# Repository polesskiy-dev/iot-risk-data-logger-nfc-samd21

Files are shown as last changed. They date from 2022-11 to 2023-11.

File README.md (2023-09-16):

# IoT Risk Data Logger

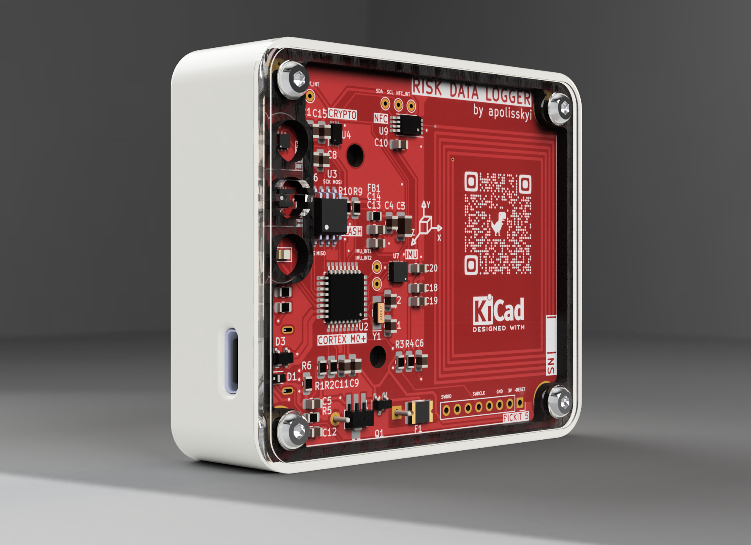
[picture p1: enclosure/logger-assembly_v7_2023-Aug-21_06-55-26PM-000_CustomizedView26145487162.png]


## Introduction
Fully open-source and open-hardware **data logger** tailored for logistics applications i.e. for cold chain monitoring systems.

## Hardware

[Schematics, PCB, enclosure, BOM, assembly documentation](https://github.com/polesskiy-dev/iot-risk-data-logger-nfc-samd21-hardware)

### Features

#### Key risk metrics:
- Temperature/Humidity [Sensirion SHT3x](https://sensirion.com/media/documents/213E6A3B/63A5A569/Datasheet_SHT3x_DIS.pdf)
- Ambient Light Sensor [TI OPT3001](https://www.ti.com/lit/ds/symlink/opt3001.pdf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)
- Shock Sensor - Accelerometer [NXP MMA8452Q](https://www.nxp.com/docs/en/data-sheet/MMA8452Q.pdf)

#### Communication:
- USB-C:
    - MSD: Device works ad a flash drive to direct log read on PC
    - CDC: Console for debug and firmware bootloader
- NFC for control through mobile app [ST ST25DV04K](https://www.st.com/resource/en/datasheet/st25dv04k.pdf)

#### Security:
- Hardware crypto [Microchip ATECC608A](https://www.microchip.com/wwwproducts/en/ATECC608A) for:
    - Firmware encryption for bootloader
    - Log data encryption
    - Authentication (X509 certificates for IoT platforms)

#### Power:
- Powered by 2xAAA batteries or USB-C (reverse polarity protection, OR source selection)
- Low Power Consumption: Ultra-low power architecture, ~ one year of data acquisition

#### Additional Features:
- 4MB SPI NOR Flash [AT25DF321](https://www.mouser.com/catalog/specsheets/atmel_doc3669.pdf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)
- RTC Clock: accurate 32.768Hz quartz oscillator
- LED: Simple indication for device states

#### Main MCU
- [Microchip ATSAMD21E18](https://www.microchip.com/en-us/product/atsamd21e18) - 32-bit ARM Cortex-M0+ MCU, 48MHz, 256KB of flash and 32KB of SRAM. Satisfies AEC-Q100, recommended for Automotive.

## Firmware

The firmware is written in C with a bare-metal approach and exclusively uses static memory allocation. It is developed on top of the [Harmony v3](https://www.microchip.com/en-us/tools-resources/configure/mplab-harmony) Embedded Software framework. Developed with [MPLAB X](https://www.microchip.com/en-us/tools-resources/develop/mplab-x-ide), [XC32](https://www.microchip.com/en-us/tools-resources/develop/mplab-xc-compilers) compiler.

### Main architecture

The source code adheres to an asynchronous, non-blocking programming style designed to achieve ultra-low power consumption.

The core mechanism revolves around handling asynchronous events from a queue and entering a low-power sleep state when the queue is empty. New events are enqueued either through interrupts (e.g., cron-scheduled sensor reads) or through the main system loop.

The architecture incorporates the following key concepts:
- [Event Loop](https://en.wikipedia.org/wiki/Event_loop)
- [Actor Model](https://en.wikipedia.org/wiki/Actor_model) - aka [Active Object](https://en.wikipedia.org/wiki/Active_object)
- [Finite-state machine](https://en.wikipedia.org/wiki/Finite-state_machine) - [Mealy](https://en.wikipedia.org/wiki/Mealy_machine) + [Moore](https://en.wikipedia.org/wiki/Moore_machine) implementation

To streamline development, an Active Object + FSM library has been implemented and is maintained in a separate [active-object-fsm](https://github.com/polesskiy-dev/active-object-fsm) repository.

## Installation
    
    $ git clone https://github.com/polesskiy-dev/iot-risk-data-logger-nfc-samd21 --recurse-submodules

Update submodules to the latest version (optional):

    $ git submodule init && git submodule update --remote # install submodules

## Some dev process photos:

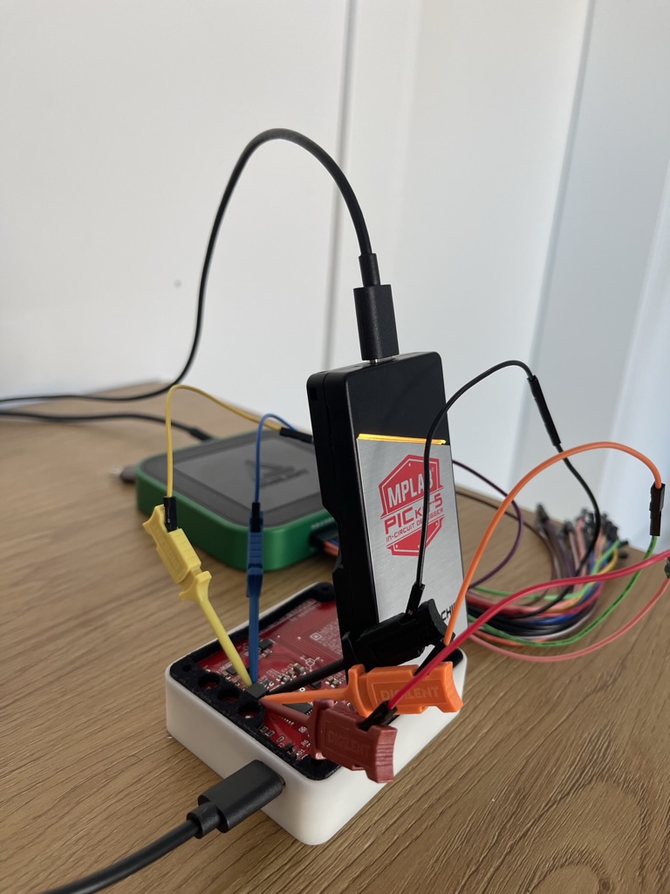
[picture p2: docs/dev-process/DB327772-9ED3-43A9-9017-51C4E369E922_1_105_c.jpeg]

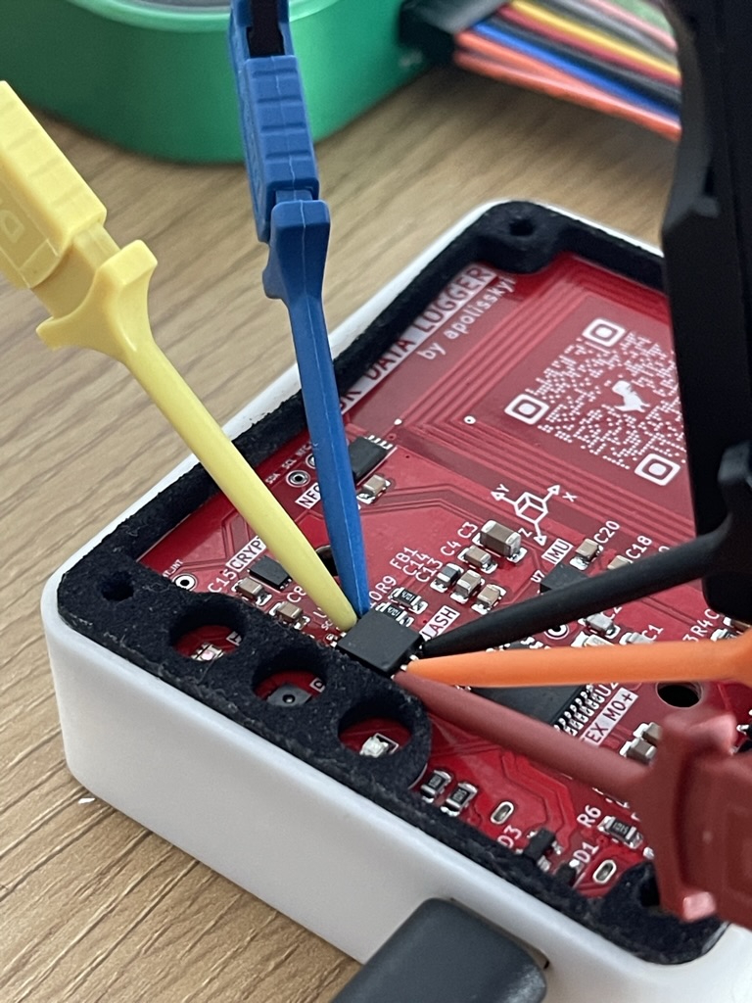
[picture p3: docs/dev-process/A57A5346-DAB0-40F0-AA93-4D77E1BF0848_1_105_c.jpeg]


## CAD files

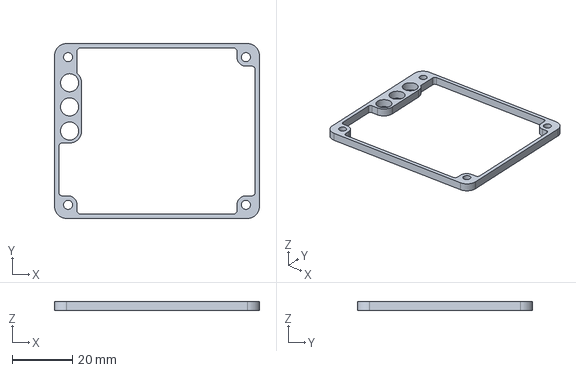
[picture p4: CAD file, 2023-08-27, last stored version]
enclosure/3D-print-manufacturing/Logger gasket v16.step
68.0 x 58.0 x 3.00 mm

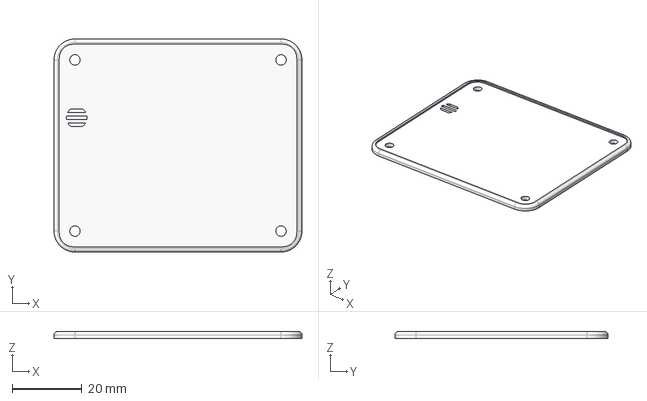
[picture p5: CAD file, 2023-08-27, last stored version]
enclosure/3D-print-manufacturing/Logger transparent top v9.step
71.0 x 61.0 x 2.00 mm

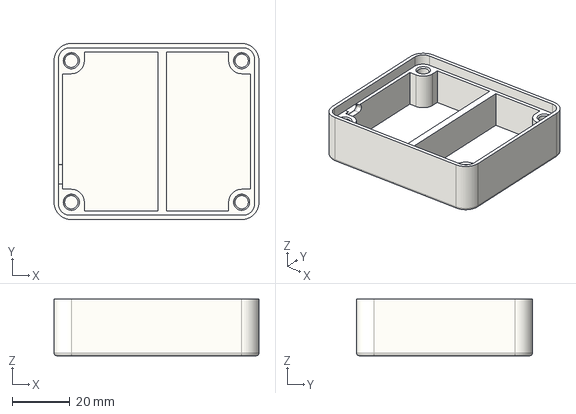
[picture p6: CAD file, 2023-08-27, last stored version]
enclosure/3D-print-manufacturing/Logger bottom enclosure v32.step
71.0 x 61.0 x 19.6 mm

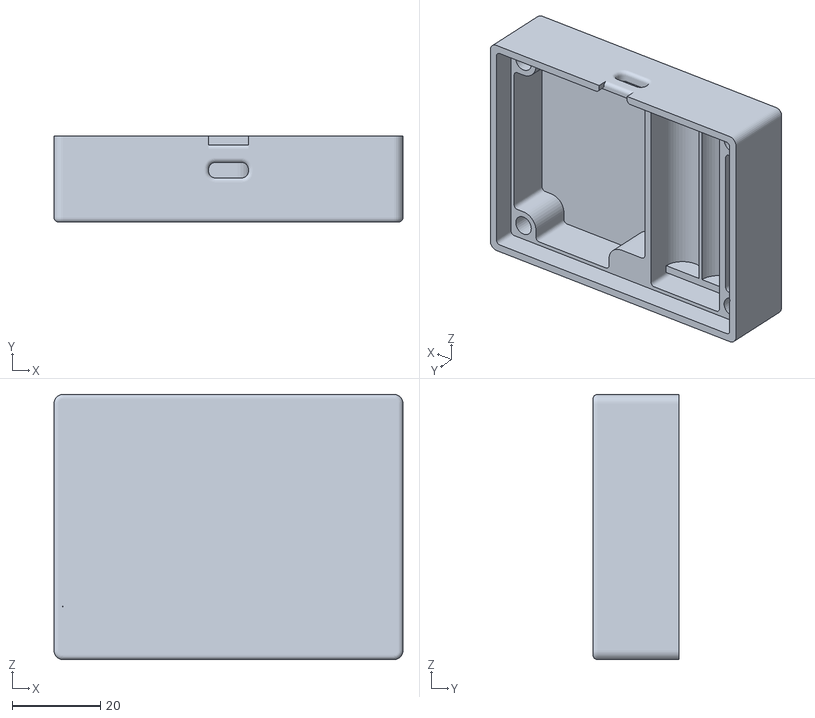
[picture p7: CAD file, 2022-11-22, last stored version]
hardware/enclosure/iot-data-logger-enclosure-bottom-base v35.stl
79.0 x 19.5 x 60.0

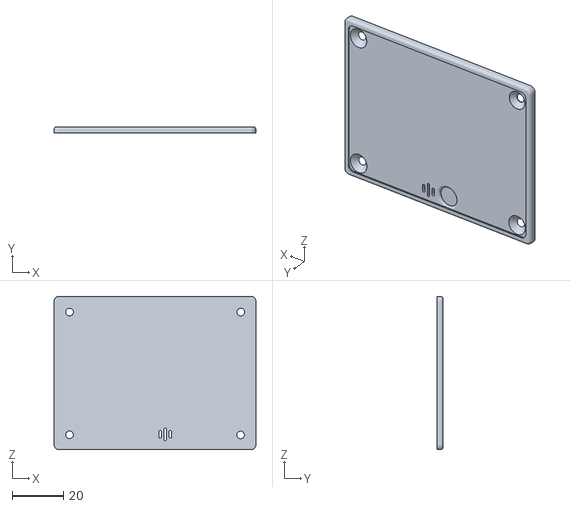
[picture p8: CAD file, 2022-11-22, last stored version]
hardware/enclosure/iot-data-logger-enclosure-top-cover v19.stl
79.0 x 2.50 x 60.0

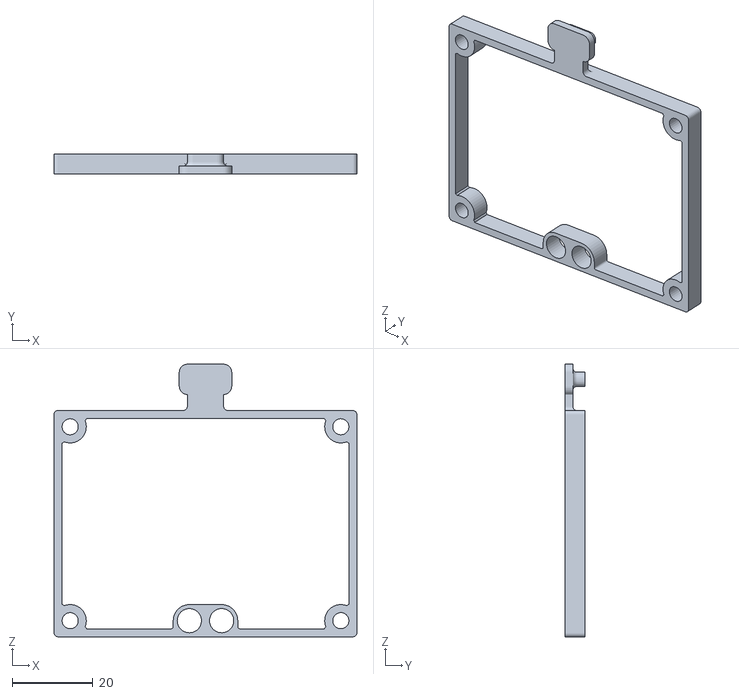
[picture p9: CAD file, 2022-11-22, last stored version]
hardware/enclosure/iot-data-logger-enclosure-gasket v30.stl
75.0 x 5.00 x 67.5

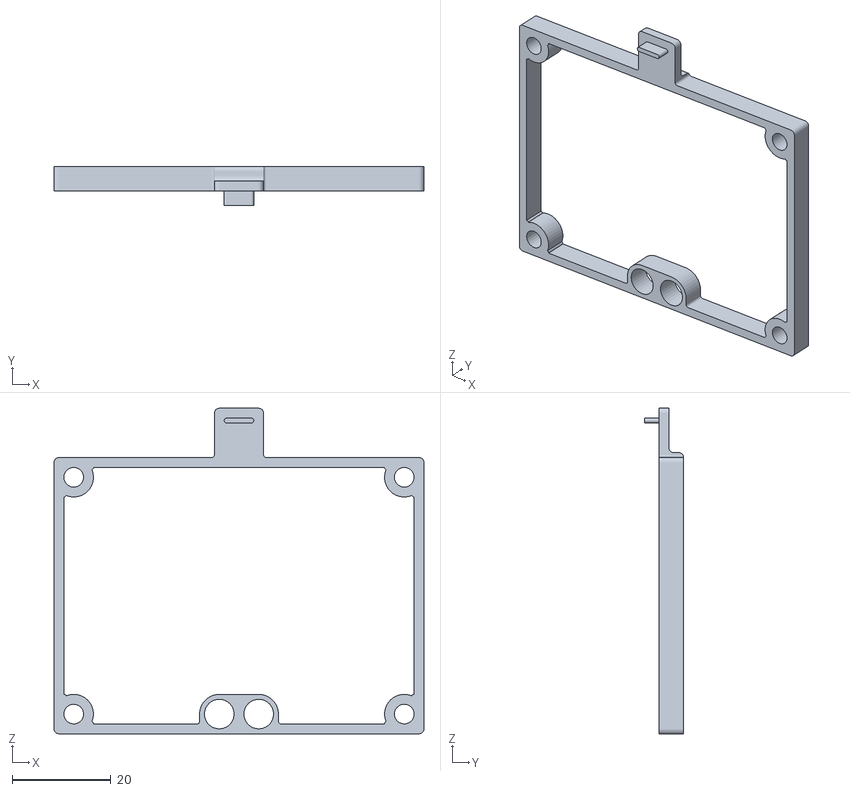
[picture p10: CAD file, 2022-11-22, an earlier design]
hardware/enclosure/iot-data-logger-enclosure-gasket v4.stl
75.0 x 8.00 x 66.0

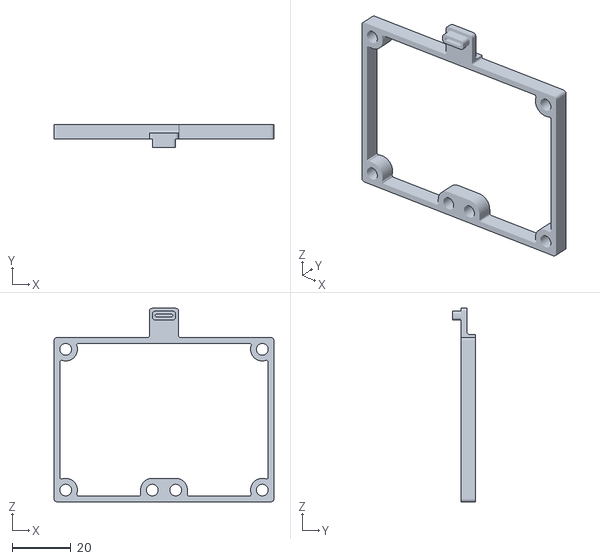
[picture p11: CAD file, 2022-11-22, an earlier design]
hardware/enclosure/iot-data-logger-enclosure-gasket v1.stl
75.0 x 8.00 x 66.0

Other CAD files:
hardware/enclosure/iot-data-logger-enclosure-top-cover v9.stl
hardware/enclosure/iot-data-logger-enclosure-bottom-base v18.stl
hardware/enclosure/iot-data-logger-enclosure-bottom-base v19.f3d
hardware/enclosure/iot-data-logger-enclosure-bottom-base v35.f3d
hardware/enclosure/iot-data-logger-enclosure-gasket v4.f3d
hardware/enclosure/iot-data-logger-enclosure-gasket v8.f3d
hardware/enclosure/iot-data-logger-enclosure-top-cover v9.f3d

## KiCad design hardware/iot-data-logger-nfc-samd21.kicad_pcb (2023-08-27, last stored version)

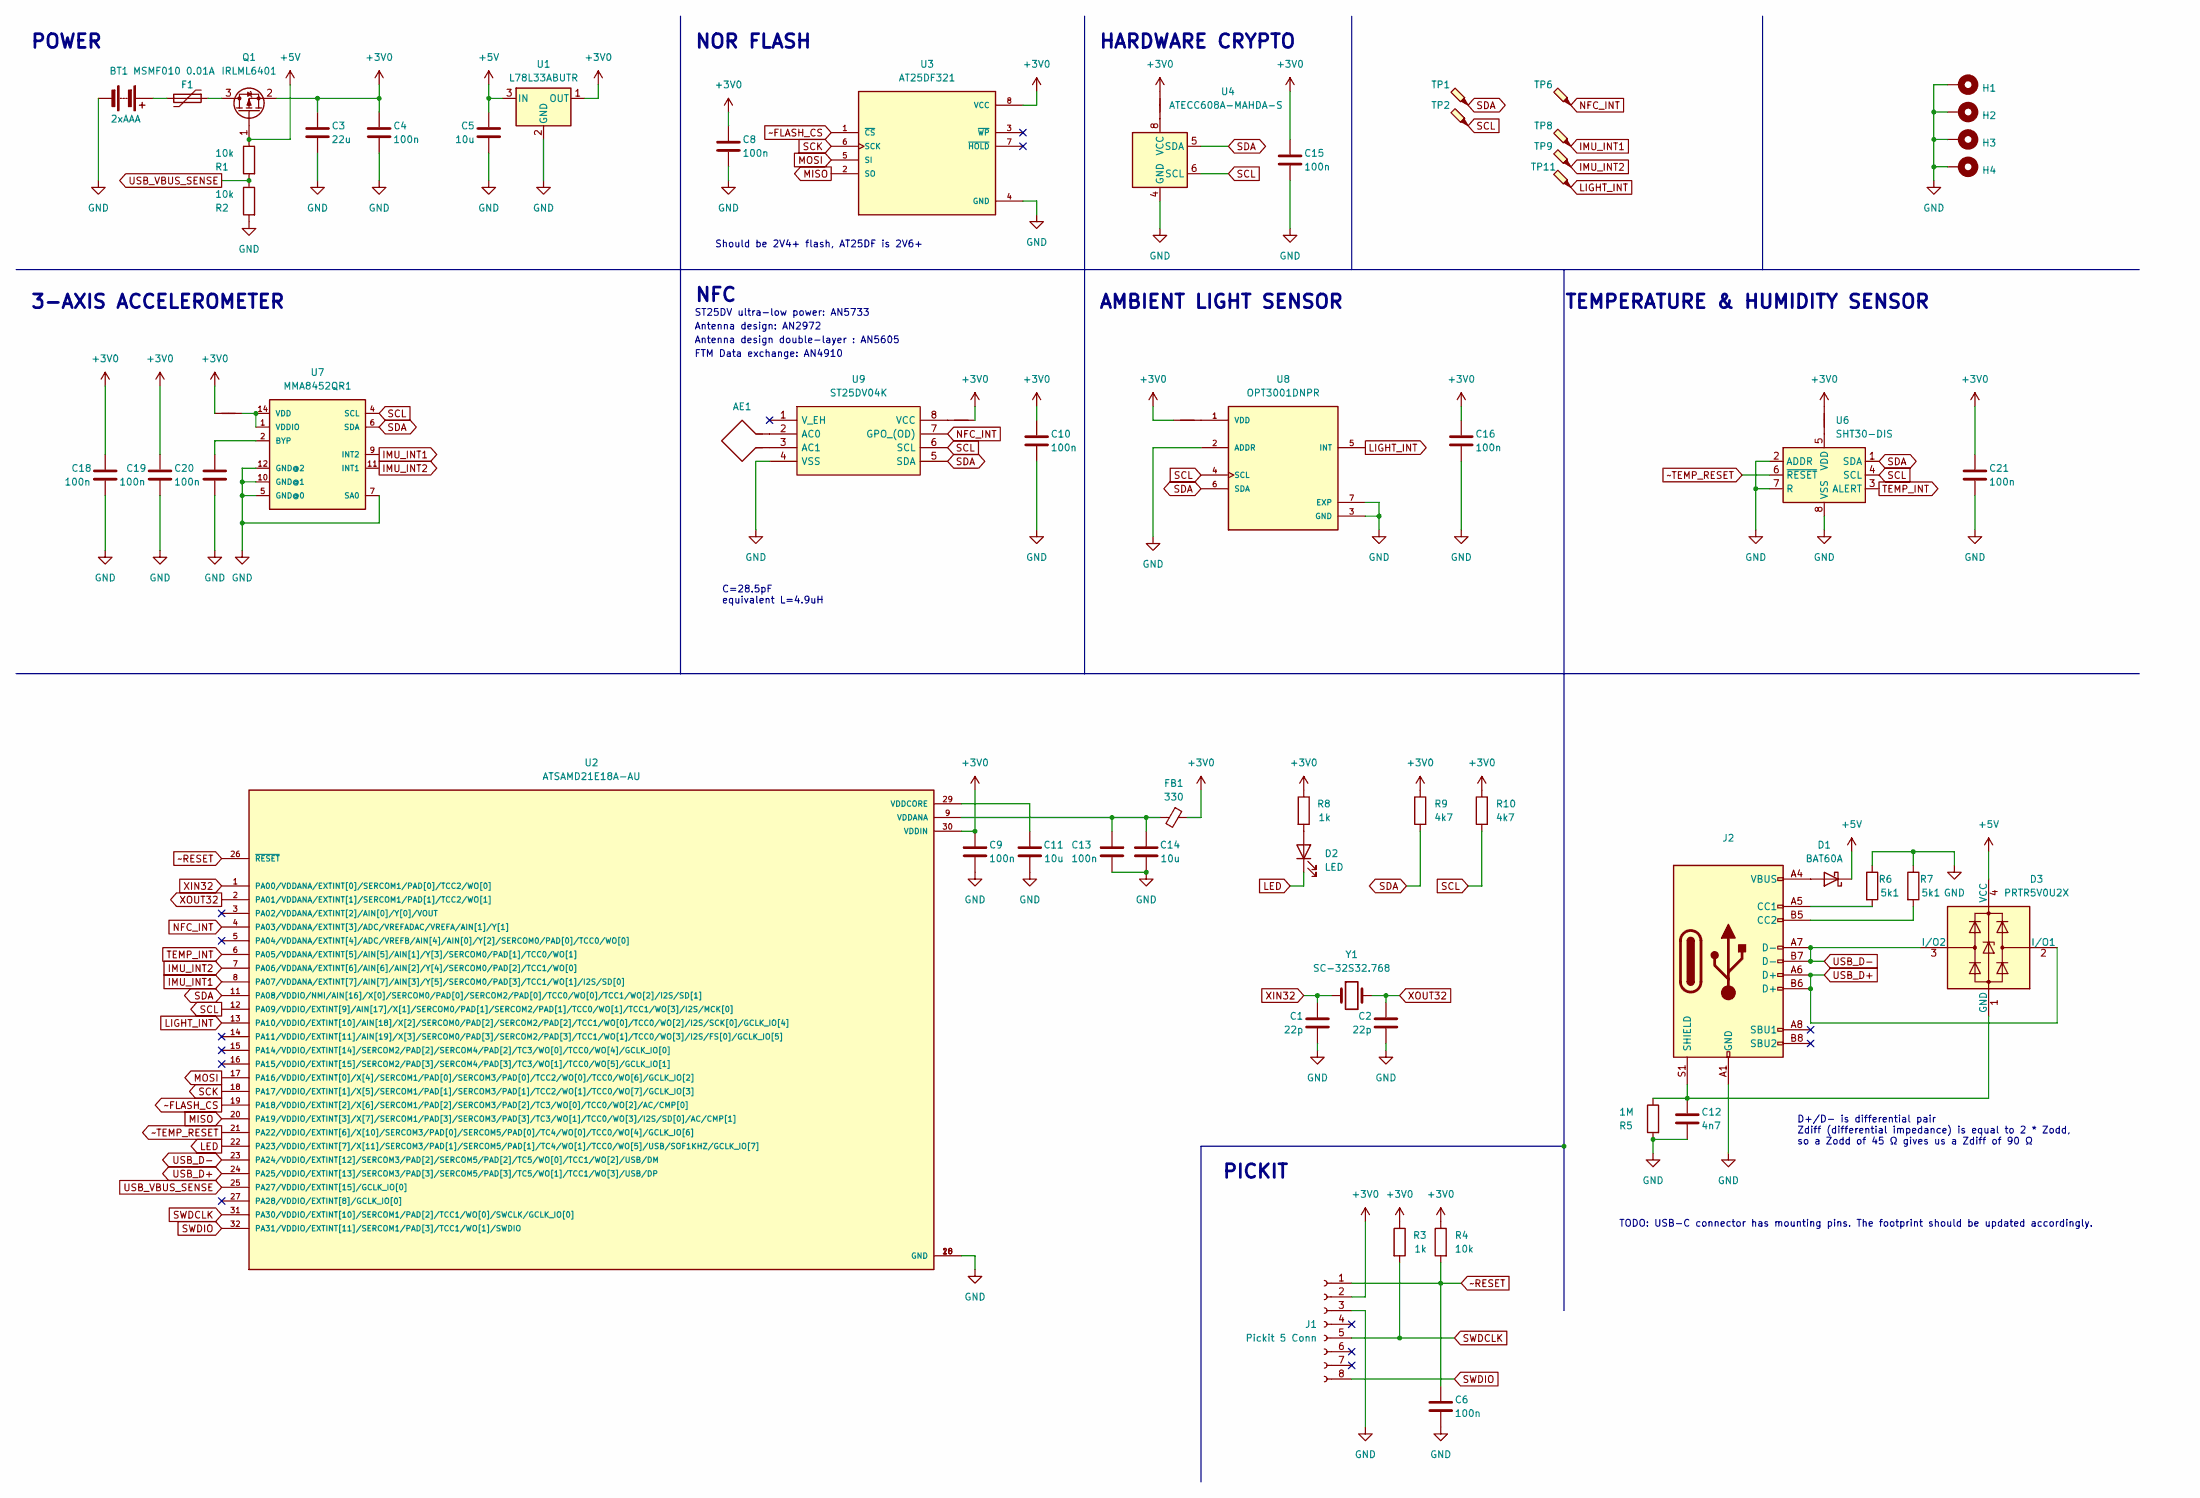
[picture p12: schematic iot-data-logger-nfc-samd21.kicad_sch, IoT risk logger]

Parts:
AE1: Antenna_Loop; ANT_NFC_30x40
BT1: 2xAAA; BatteryHolder_Keystone_2468_2xAAA; Part Keystone 2468; LCSC Part C254917
C1, C2: 22p; C_0805_2012Metric_Pad1.18x1.45mm_HandSolder; Part CL21C220JBANNNC; LCSC Part C1804
C3: 22u; C_1206_3216Metric_Pad1.33x1.80mm_HandSolder; Part CL31A226KAHNNNE; LCSC Part C12891
C4, C6, C8, C9, C10, C13, C15, C16, C18, C19, C20, C21: 100n; C_0805_2012Metric_Pad1.18x1.45mm_HandSolder; Part CL21B104KBCNNNC; LCSC Part C1711
C5, C11, C14: 10u; C_0805_2012Metric_Pad1.18x1.45mm_HandSolder; Part CL21A106KOQNNNE; LCSC Part C1713
C12: 4n7; C_0805_2012Metric_Pad1.18x1.45mm_HandSolder; Part CL21B472KBANNNC; LCSC Part C50131
D1: BAT60A; D_SOD-323_HandSoldering; Part BAT60A; LCSC Part C5355496
D2: LED; LED_0805_2012Metric_Pad1.15x1.40mm_HandSolder; Part NCD0805G1; LCSC Part C84260
D3: PRTR5V0U2X; SOT-143; Part PRTR5V0U2X; LCSC Part C2827688
F1: MSMF010 0.01A; Fuse_1812_4532Metric_Pad1.30x3.40mm_HandSolder; Part MF-MSMF010-2; LCSC Part C12430
FB1: 330; R_0805_2012Metric_Pad1.20x1.40mm_HandSolder; Part BLM21PG331SN1D; LCSC Part C47130
H1, H2, H3, H4: MountingHole_Pad; MountingHole_3.2mm_M3_Pad_Via
J1: Pickit 5 Conn; PinSocket_1x08_P2.54mm_Vertical
J2: USB Type-C; USB_C_Receptacle_XKB_U262-16XN-4BVC11; Part KH-TYPE-C-16P; LCSC Part C709357
NT1, NT2, NT3, NT4, NT5: NetTie_2; NetTie-2_SMD_Pad0.5mm
Q1: IRLML6401; SOT-23; Part IRLML6401TRPBF; LCSC Part C3034
R1, R2, R4: 10k; R_0805_2012Metric_Pad1.20x1.40mm_HandSolder; Part RC0805FR-0710KL; LCSC Part C84376
R3, R8: 1k; R_0805_2012Metric_Pad1.20x1.40mm_HandSolder; Part RC0805FR-071KL; LCSC Part C95781
R5: 1M; R_0805_2012Metric_Pad1.20x1.40mm_HandSolder; Part RC0805FR-071ML; LCSC Part C107700
R6, R7: 5k1; R_0805_2012Metric_Pad1.20x1.40mm_HandSolder; Part RC0805FR-075K1L; LCSC Part C84375
R9, R10: 4k7; R_0805_2012Metric_Pad1.20x1.40mm_HandSolder; Part RC0805FR-074K7L; LCSC Part C60816
TP1, TP2, TP6, TP8, TP9, TP11: TestPoint_Probe; TestPoint_THTPad_D1.5mm_Drill0.7mm
U1: L78L33ABUTR; SOT-89-3_Handsoldering; Part L78L33ABUTR; LCSC Part C81362
U2: ATSAMD21E18A-AU; TQFP-32_7x7mm_P0.8mm; Part ATSAMD21E18A-AU; LCSC Part C618771
U3: AT25DF321; SOP-8_5.28x5.23mm_P1.27mm; Part AT25DF321A-SH-T; LCSC Part C6490
U4: ATECC608A-MAHDA-S; DFN-8-1EP_3x2mm_P0.5mm_EP1.3x1.5mm; Part ATECC608A-MAHDA-S; LCSC Part C616908
U6: SHT30-DIS; Sensirion_DFN-8-1EP_2.5x2.5mm_P0.5mm_EP1.1x1.7mm; Part SHT30-DIS-B10KS; LCSC Part C2687423
U7: MMA8452QR1; XDCR_MMA8452QR1; Part MMA8452QR1; LCSC Part C11360
U8: OPT3001DNPR; SON65P200X200X65-7N; Part OPT3001DNPR; LCSC Part C90462
U9: ST25DV04K; TSSOP-8_4.4x3mm_P0.65mm; Part ST25DV04K-IER6T3; LCSC Part C2654816
Y1: SC-32S32.768; Crystal_SMD_EuroQuartz_EQ161-2Pin_3.2x1.5mm_HandSoldering; Part SC-32S32.768kHz20PPM12.5pF; LCSC Part C97606

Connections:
+3V0: C3.1, C4.1, C8.1, C9.1, C10.1, C15.1, C16.1, C18.1, C19.1, C21.1, FB1.1, J1.2, NT1.1, NT2.1, NT3.2, NT4.1, NT5.2, Q1.2 (S), R3.1, R4.1, R8.1, R9.1, R10.1, U1.1 (OUT), U2.30 (VDDIN), U3.8 (VCC)
+5V: C5.1, D1.1 (K), D3.4 (VCC), Q1.1 (G), R1.1, U1.3 (IN)
GND: BT1.2 (-), C1.2, C2.2, C3.2, C4.2, C5.2, C6.2, C8.2, C9.2, C10.2, C11.2, C12.2, C13.2, C14.2, C15.2, C16.2, C18.2, C19.2, C20.2, C21.2, H1.1, H2.1, H3.1, H4.1, J1.3, J2.A1 (GND), J2.A12 (GND), J2.B1 (GND), J2.B12 (GND), R2.2, R5.2, R6.1, R7.1, U1.2 (GND), U2.10 (GND), U2.28 (GND), U3.4 (GND), U4.4 (GND), U6.2 (ADDR), U6.7 (R), U6.8 (VSS), U6.9 (VSS), U7.5 (GND@0), U7.7 (SA0), U7.10 (GND@1), U7.12 (GND@2), U8.2 (ADDR), U8.3 (GND), U8.7 (EXP), U9.4 (VSS)
IMU_INT1: TP8.1, U2.8 (PA07/VDDANA/EXTINT[7]/AIN[7]/AIN[3]/Y[5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), U7.9 (INT2)
IMU_INT2: TP9.1, U2.7 (PA06/VDDANA/EXTINT[6]/AIN[6]/AIN[2]/Y[4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), U7.11 (INT1)
LED: D2.1 (K), U2.22 (PA23/VDDIO/EXTINT[7]/X[11]/SERCOM3/PAD[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)
LIGHT_INT: TP11.1, U2.13 (PA10/VDDIO/EXTINT[10]/AIN[18]/X[2]/SERC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), U8.5 (INT)
MISO: U2.20 (PA19/VDDIO/EXTINT[3]/X[7]/SERCOM1/PAD[3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), U3.2 (SO)
MOSI: U2.17 (PA16/VDDIO/EXTINT[0]/X[4]/SERCOM1/PAD[0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), U3.5 (SI)
NFC_INT: TP6.1, U2.4 (PA03/VDDANA/EXTINT[3]/ADC/VREFADAC/VREF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), U9.7 (GPO_(OD))
unnamed: BT1.1 (+), F1.2
unnamed: D1.2 (A), J2.A4 (VBUS), J2.A9 (VBUS), J2.B4 (VBUS), J2.B9 (VBUS)
unnamed: D2.2 (A), R8.2
unnamed: C12.1, D3.1 (GND), J2.S1 (SHIELD), R5.1
unnamed: J2.A5 (CC1), R6.2
unnamed: J2.B5 (CC2), R7.2
unnamed: F1.1, Q1.3 (D)
unnamed: C13.1, C14.1, FB1.2, U2.9 (VDDANA)
unnamed: C11.1, U2.29 (VDDCORE)
unnamed: NT1.2, U4.8 (VCC)
unnamed: NT5.1, U6.5 (VDD)
unnamed: C20.1, U7.2 (BYP)
unnamed: NT2.2, U7.1 (VDDIO), U7.14 (VDD)
unnamed: NT4.2, U8.1 (VDD)
unnamed: AE1.2, U9.2 (AC0)
unnamed: AE1.1, U9.3 (AC1)
unnamed: NT3.1, U9.8 (VCC)
SCK: U2.18 (PA17/VDDIO/EXTINT[1]/X[5]/SERCOM1/PAD[1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), U3.6 (SCK)
SCL: R10.2, TP2.1, U2.12 (PA09/VDDIO/EXTINT[9]/AIN[17]/X[1]/SERCO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), U4.6 (SCL), U6.4 (SCL), U7.4 (SCL), U8.4 (SCL), U9.6 (SCL)
SDA: R9.2, TP1.1, U2.11 (PA08/VDDIO/NMI/AIN[16]/X[0]/SERCOM0/PAD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), U4.5 (SDA), U6.1 (SDA), U7.6 (SDA), U8.6 (SDA), U9.5 (SDA)
SWDCLK: J1.5, R3.2, U2.31 (PA30/VDDIO/EXTINT[10]/SERCOM1/PAD[2]/TC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)
SWDIO: J1.8, U2.32 (PA31/VDDIO/EXTINT[11]/SERCOM1/PAD[3]/TC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)
TEMP_INT: U2.6 (PA05/VDDANA/EXTINT[5]/AIN[5]/AIN[1]/Y[3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), U6.3 (ALERT)
USB_D+: D3.2 (I/O1), J2.A6 (D+), J2.B6 (D+), U2.24 (PA25/VDDIO/EXTINT[13]/SERCOM3/PAD[3]/SE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)
USB_D-: D3.3 (I/O2), J2.A7 (D-), J2.B7 (D-), U2.23 (PA24/VDDIO/EXTINT[12]/SERCOM3/PAD[2]/SE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)
USB_VBUS_SENSE: R1.2, R2.1, U2.25 (PA27/VDDIO/EXTINT[15]/GCLK_IO[0])
XIN32: C1.1, U2.1 (PA00/VDDANA/EXTINT[0]/SERCOM1/PAD[0]/TC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), Y1.1
XOUT32: C2.1, U2.2 (PA01/VDDANA/EXTINT[1]/SERCOM1/PAD[1]/TC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), Y1.2
~FLASH_CS: U2.19 (PA18/VDDIO/EXTINT[2]/X[6]/SERCOM1/PAD[2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), U3.1 (~CS)
~RESET: C6.1, J1.1, R4.2, U2.26 (~RESET)
~TEMP_RESET: U2.21 (PA22/VDDIO/EXTINT[6]/X[10]/SERCOM3/PAD[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), U6.6 (~RESET)

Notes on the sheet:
Antenna design double-layer : AN5605
HARDWARE CRYPTO
FTM Data exchange: AN4910
TODO: USB-C connector has mounting pins. The footprint should be updated accordingly.
NFC
С=28.5pF equivalent L=4.9uH
D+/D- is differential pair Zdiff (differential impedance) is equal to 2 * Zodd, so a Zodd of 45 Ω gives us a Zdiff of 90 Ω
Antenna design: AN2972
POWER
ST25DV ultra-low power: AN5733
Should be 2V4+ flash, AT25DF is 2V6+
3-AXIS ACCELEROMETER
PICKIT
NOR FLASH
TEMPERATURE & HUMIDITY SENSOR
AMBIENT LIGHT SENSOR

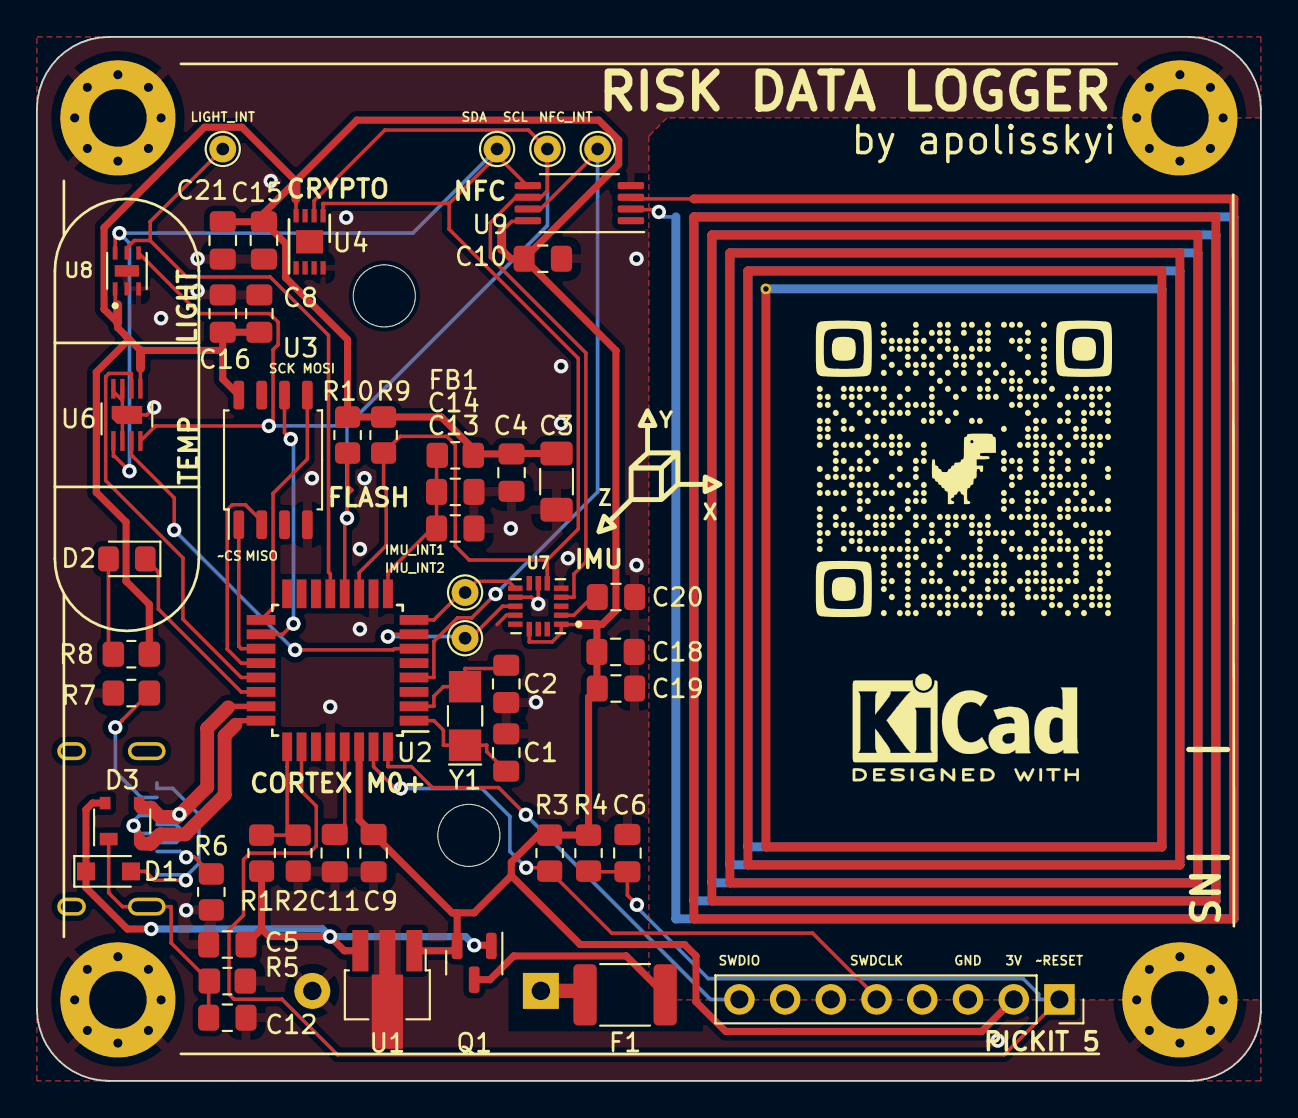
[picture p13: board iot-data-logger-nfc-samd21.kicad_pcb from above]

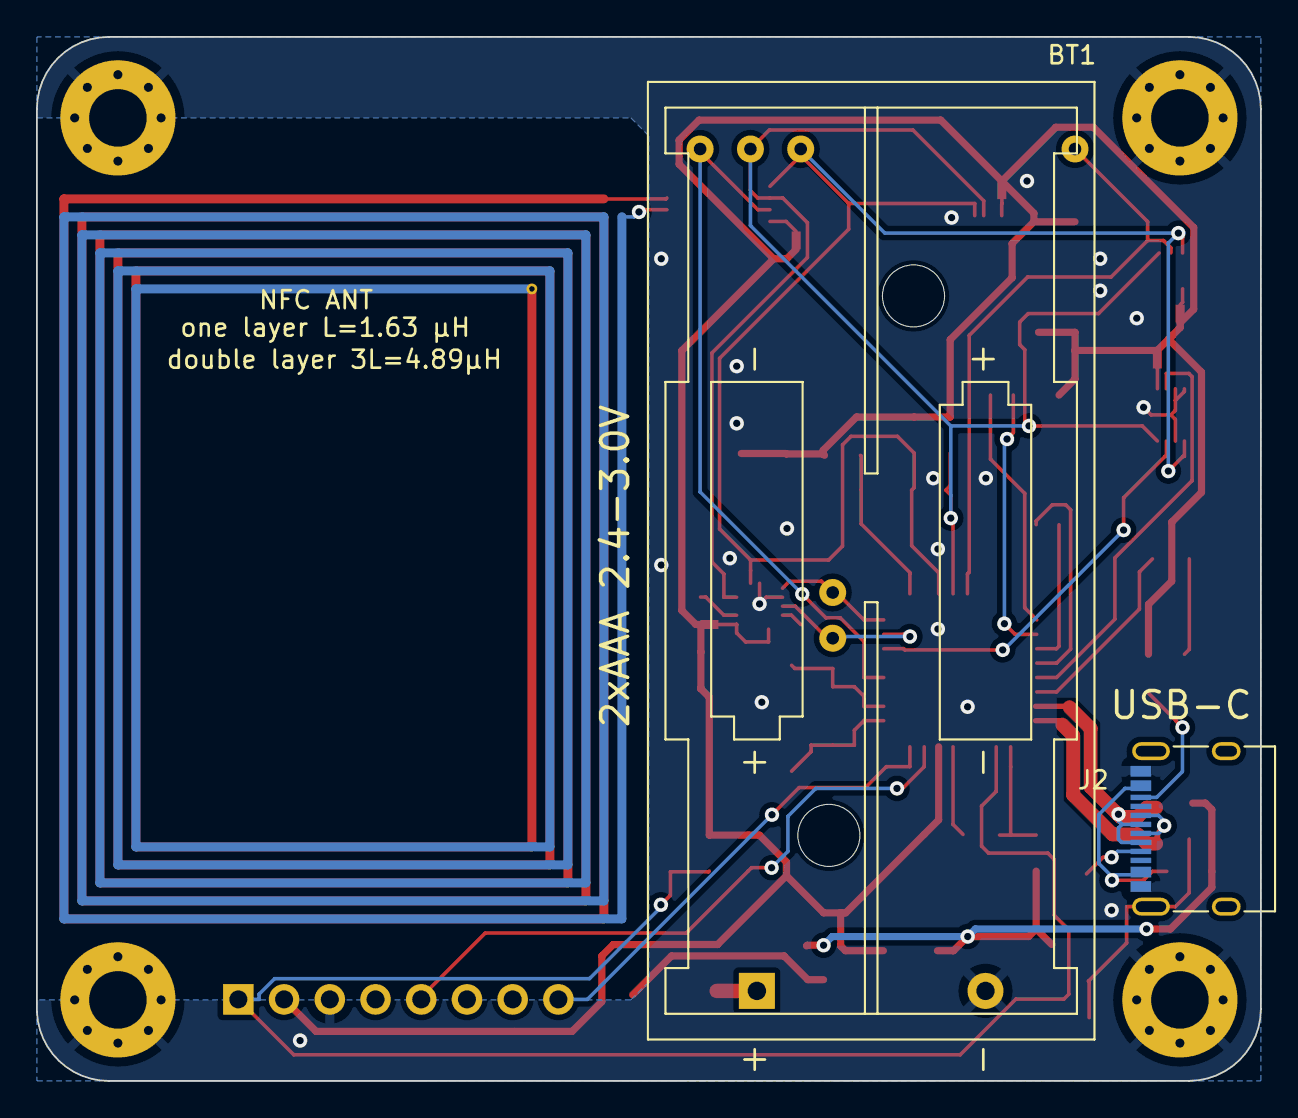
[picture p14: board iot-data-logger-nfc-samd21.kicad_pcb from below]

Board: 2 copper layers, 68.0 x 58.0 mm, 64 parts (2 on the bottom side), 41 nets.

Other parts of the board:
G04: LOGO

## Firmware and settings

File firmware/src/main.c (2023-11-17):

/*******************************************************************************
  Main Source File

  Company:
    Microchip Technology Inc.

  File Name:
    main.c

  Summary:
    This file contains the "main" function for a project.

  Description:
    This file contains the "main" function for a project.  The
    "main" function calls the "SYS_Initialize" function to initialize the state
    machines of all modules in the system
 *******************************************************************************/

// *****************************************************************************
// *****************************************************************************
// Section: Included Files
// *****************************************************************************
// *****************************************************************************

#include <stddef.h>                     // Defines NULL
#include <stdbool.h>                    // Defines true
#include <stdlib.h>                     // Defines EXIT_FAILURE

#include "definitions.h"                // SYS function prototypes
#include "init_manager/init_manager.h"
#include "config/common.defs.h"         // Common definitions
#include "app_manager/app_manager.h"

void _toggleLED(uintptr_t context) {
    _LED_Toggle();
}


// *****************************************************************************
// *****************************************************************************
// Section: Main Entry Point
// *****************************************************************************
// *****************************************************************************
int main(void) {
    /* Initialize all modules */
    SYS_Initialize(NULL);

    // Debug: verify that app isn't stuck
//    SYS_TIME_CallbackRegisterMS(_toggleLED, (uintptr_t) NULL, 1000, SYS_TIME_PERIODIC);

    while (true) {
        /* Maintain state machines of all polled MPLAB Harmony modules. */
        SYS_Tasks();

        INIT_Tasks();
        APP_Tasks();
    }

    /* Execution should not come here during normal operation */

    return (EXIT_FAILURE);
}


/*******************************************************************************
 End of File
*/

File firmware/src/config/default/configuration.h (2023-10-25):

/*******************************************************************************
  System Configuration Header

  File Name:
    configuration.h

  Summary:
    Build-time configuration header for the system defined by this project.

  Description:
    An MPLAB Project may have multiple configurations.  This file defines the
    build-time options for a single configuration.

  Remarks:
    This configuration header must not define any prototypes or data
    definitions (or include any files that do).  It only provides macro
    definitions for build-time configuration options

*******************************************************************************/

// DOM-IGNORE-BEGIN
/*******************************************************************************
* Copyright (C) 2018 Microchip Technology Inc. and its subsidiaries.
*
* Subject to your compliance with these terms, you may use Microchip software
* and any derivatives exclusively with Microchip products. It is your
* responsibility to comply with third party license terms applicable to your
* use of third party software (including open source software) that may
* accompany Microchip software.
*
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
* IN NO EVENT WILL MICROCHIP BE LIABLE FOR ANY INDIRECT, SPECIAL, PUNITIVE,
* INCIDENTAL OR CONSEQUENTIAL LOSS, DAMAGE, COST OR EXPENSE OF ANY KIND
* WHATSOEVER RELATED TO THE SOFTWARE, HOWEVER CAUSED, EVEN IF MICROCHIP HAS
* BEEN ADVISED OF THE POSSIBILITY OR THE DAMAGES ARE FORESEEABLE. TO THE
* FULLEST EXTENT ALLOWED BY LAW, MICROCHIP'S TOTAL LIABILITY ON ALL CLAIMS IN
* ANY WAY RELATED TO THIS SOFTWARE WILL NOT EXCEED THE AMOUNT OF FEES, IF ANY,
* THAT YOU HAVE PAID DIRECTLY TO MICROCHIP FOR THIS SOFTWARE.
*******************************************************************************/
// DOM-IGNORE-END

#ifndef CONFIGURATION_H
#define CONFIGURATION_H

// *****************************************************************************
// *****************************************************************************
// Section: Included Files
// *****************************************************************************
// *****************************************************************************
/*  This section Includes other configuration headers necessary to completely
    define this configuration.
*/

#include "user.h"
#include "device.h"

// DOM-IGNORE-BEGIN
#ifdef __cplusplus  // Provide C++ Compatibility

extern "C" {

#endif
// DOM-IGNORE-END

// *****************************************************************************
// *****************************************************************************
// Section: System Configuration
// *****************************************************************************
// *****************************************************************************



// *****************************************************************************
// *****************************************************************************
// Section: System Service Configuration
// *****************************************************************************
// *****************************************************************************
/* TIME System Service Configuration Options */
#define SYS_TIME_INDEX_0                            (0)
#define SYS_TIME_MAX_TIMERS                         (5)
#define SYS_TIME_HW_COUNTER_WIDTH                   (16)
#define SYS_TIME_HW_COUNTER_PERIOD                  (0xFFFFU)
#define SYS_TIME_HW_COUNTER_HALF_PERIOD             (SYS_TIME_HW_COUNTER_PERIOD>>1)
#define SYS_TIME_CPU_CLOCK_FREQUENCY                (47972352)
#define SYS_TIME_COMPARE_UPDATE_EXECUTION_CYCLES    (200)

#define SYS_CONSOLE_INDEX_0                       0

/* RX buffer size has one additional element for the empty spot needed in circular buffer */
#define SYS_CONSOLE_USB_CDC_RD_BUFFER_SIZE_IDX0    129

/* TX buffer size has one additional element for the empty spot needed in circular buffer */
#define SYS_CONSOLE_USB_CDC_WR_BUFFER_SIZE_IDX0    129



#define SYS_DEBUG_ENABLE
#define SYS_DEBUG_GLOBAL_ERROR_LEVEL       SYS_ERROR_DEBUG
#define SYS_DEBUG_BUFFER_DMA_READY
#define SYS_DEBUG_USE_CONSOLE


#define SYS_CONSOLE_DEVICE_MAX_INSTANCES   			(1U)
#define SYS_CONSOLE_UART_MAX_INSTANCES 	   			(0U)
#define SYS_CONSOLE_USB_CDC_MAX_INSTANCES 	   		(1U)
#define SYS_CONSOLE_PRINT_BUFFER_SIZE        		(200U)

#define SYS_CONSOLE_USB_CDC_READ_WRITE_BUFFER_SIZE 	(64)
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

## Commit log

2022-10-25 PCB: add qr to github repo
    [iot-data-logger-nfc-samd21.kicad_pcb]
2022-11-22 add enclosure, bom docs
    [iot-data-logger-enclosure-bottom-base v18.stl, iot-data-logger-enclosure-bottom-base v19.f3d, iot-data-logger-enclosure-bottom-base v35.f3d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]
2022-11-22 add interactive BOM link
2022-11-26 generate Microchip Harmony 3 project, configure clock source
    [pin_configurations.csv]
2022-11-26 add gpio pins assignment
    [pin_configurations.csv]
2022-11-27 configure SERCOM0, SERCOM1, RTC peripherial libraries, draft FreeRTOS config
    [iot-data-logger-nfc-samd21.kicad_sch, pin_configurations.csv]
2022-11-27 add TIME, I2C driver to project graph, set USB ID
2022-11-28 add FreeRTOS tasks draf in project graph
    [configuration.h]
2022-11-28 get rid of Harmony v3 USB example temperature read legacy, make project compilable
2023-01-24 upgrade PCB with CS pin, NFC pull-up
    [iot-data-logger-nfc-samd21.dsn, iot-data-logger-nfc-samd21.kicad_pcb, iot-data-logger-nfc-samd21.kicad_sch]
2023-01-26 update PCB images
    [bom.csv, designators.csv, positions.csv]
2023-02-04 pcb images: replace by renders
2023-08-09 shematics, PCB, BOM: update, prepare for SMT order, change light sensor to OPT3001
    [bom.csv, designators.csv, iot-data-logger-nfc-samd21 - iot-data-logger-nfc-samd21-BOM.csv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]
2023-08-27 update hardware, add enclosure drawings
    [Logger bottom enclosure v32.step, Logger gasket v16.step, Logger transparent top v9.step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]
2023-08-28 docs: add enclosure README draft
2023-08-28 docs: enclosure, add more pictures to README
2023-09-07 extracted hardware to https://github.com/polesskiy-dev/iot-risk-data-logger-nfc-samd21-hardware
    [freerouting.dsn, iot-data-logger-nfc-samd21 - iot-data-logger-nfc-samd21-BOM.csv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]
2023-09-07 fresh project bootstraped
    [configuration.h, pin_configurations.csv]
2023-09-11 initial: set _LED and TIME, initial blinky works
    [configuration.h, pin_configurations.csv]
2023-09-11 initial: setup clocks
    [configuration.h]
2023-09-11 initial: setup pins
    [pin_configurations.csv]
2023-09-11 initial: add SERCOM0, I2C, RTC, PM, EIC, TODO: EIC check 5,6,7 channels
    [configuration.h, pin_configurations.csv]
2023-09-11 initial: add SERCOM1, SPI AT25DF, MEMORY
    [configuration.h]
2023-09-11 initial: add USB: MSD, CDC, CONSOLE, DEBUG
    [configuration.h]
2023-09-12 add SHT3x initial sensor module, NFC initial module
2023-09-14 STORAGE, Boot sector: read, check, write. Temporary remove USB MSD
    [configuration.h]
2023-09-16 create INIT Actor, add USB MSD
    [configuration.h]
2023-09-16 enclosure: move to hardware repo
    [Logger bottom enclosure v32.step, Logger gasket v16.step, Logger transparent top v9.step]
2023-09-24 NFC: add interrupt status read on GPO pulse, enable GPO interrupt pin _NFC_INT
    [configuration.h]
2023-10-21 NFC: extract 'prepare mailbox' flow to sub-fsm
2023-10-25 NFC: add GPO interrupt
2023-10-25 APP,USB Managers: add main app and USB manager
    [configuration.h]
2023-10-25 USB: Add USB_VBUS_SENSE Pin Interrupt handle
